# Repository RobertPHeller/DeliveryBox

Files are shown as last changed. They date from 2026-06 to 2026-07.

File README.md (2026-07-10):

# Delivery Box -- A lockable box for delivery prople to deliver stuff to.

This is a design for a delivery box -- a lockable box that delivery drivers
can place deliveries into, using one-time codes, where the delivery can be 
securely  housed  until the resident can retrieve  them.  This is to allow for
secure deliveries when noone is home to receive them.  The box will be
lockable and can be secured.  This will make deliveries secure from 
"porch pirates".

- [BoxDesign](BoxDesign/)

- [Circuit](Circuit/)

- [Firmware](DeliveryBoxFirmware/)

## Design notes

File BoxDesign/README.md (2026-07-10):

# This is the box design

The box would be made of CDX (exterier grade) 3/8 plywood with internier 2x2
framing, 20 inches by 24 inches by 30 inches, which should be large enough
for  more  deliveries.  It  will  have  wheels  to  make  moving  it  easy  --
partitularly handy for people with long driveways.

Here is a view of the box:

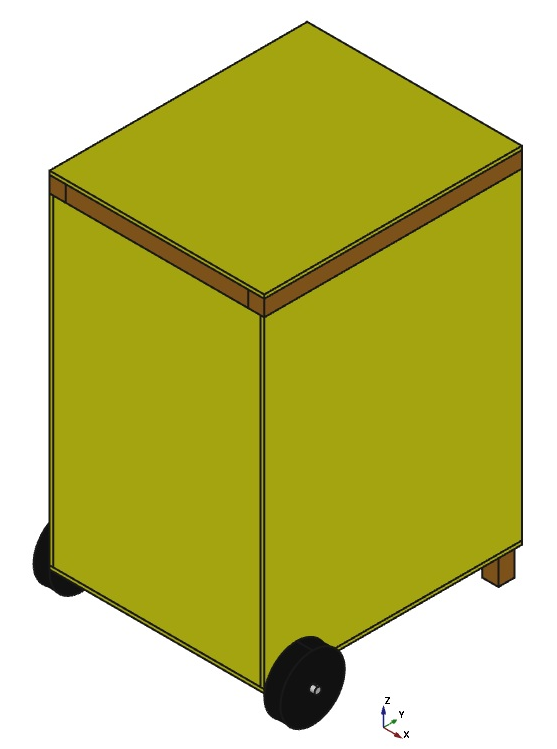
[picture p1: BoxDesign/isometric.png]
Isometric view of box


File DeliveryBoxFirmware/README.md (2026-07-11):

# This is the firmware

Target dev board: Adafruit Feather ESP32S3, No Psram version (8M flash).
 
This firmware manages the lock via a servo.  There is a numeric keypad and
an eight character 14-segment display.
 
The lock uses 8-digit codes to unlock the box.  There is one master code 
and any number of one-time codes.  The one time codes are given to delivery
drivers when a delivery is scheduled.  Once the driver uses the code to 
deliver the parcel, the code is removed and can't be used again.

The  firmware  can use  both  Blutooth  (BLE)  and  WiFi for  configuring  and
management.

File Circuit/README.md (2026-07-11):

# This is the circuit design

The circuit design uses these parts: 

1. A main board containing an Adafruit ESP32-S3 Feather and connection headers
for a servo  and the  keypad  (there is a  STEMMA/QWIC  connector  for the I2C
connection to the Display Module on th Feather board).  The Adafruit  ESP32-S3
Feather  includes a JST battery  connection and includes a LiPo battery charge
circuit.

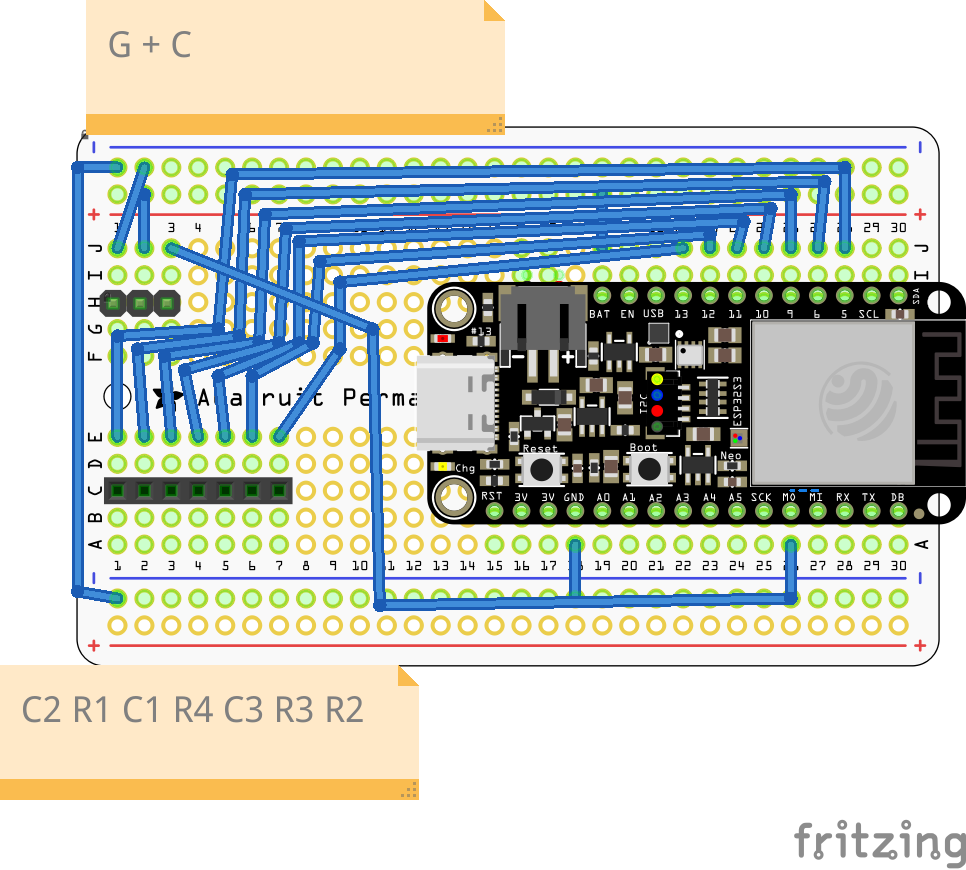
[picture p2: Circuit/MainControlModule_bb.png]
Main board fritzing module


2.  A  display  module  with  a  HT16K33   breakout  and  4  dual   14-segment
alphanumberic display modules.

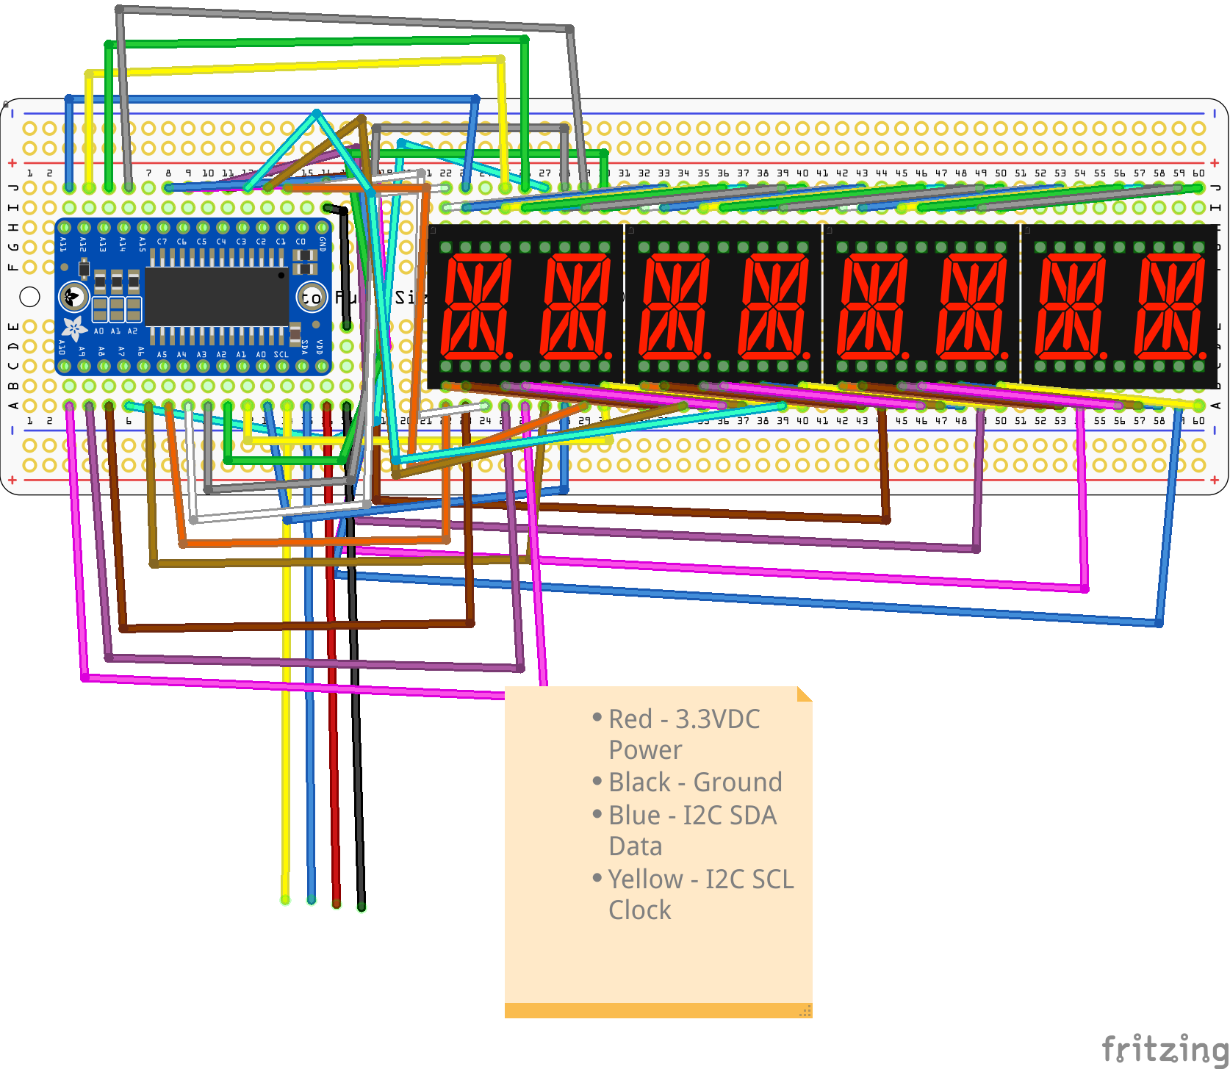
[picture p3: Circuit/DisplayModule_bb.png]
Display board fritzing module


3.  A 12-key keypad board.

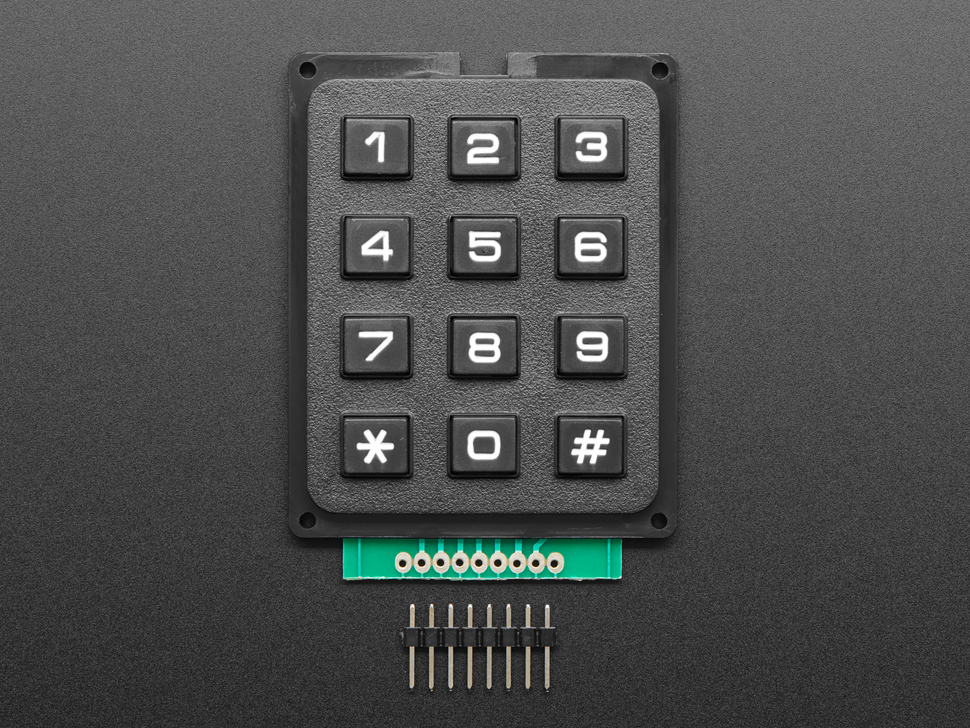
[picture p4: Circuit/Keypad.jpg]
3x4 Keypad


4. A high torque metal gear servo will be used to operate a lock.

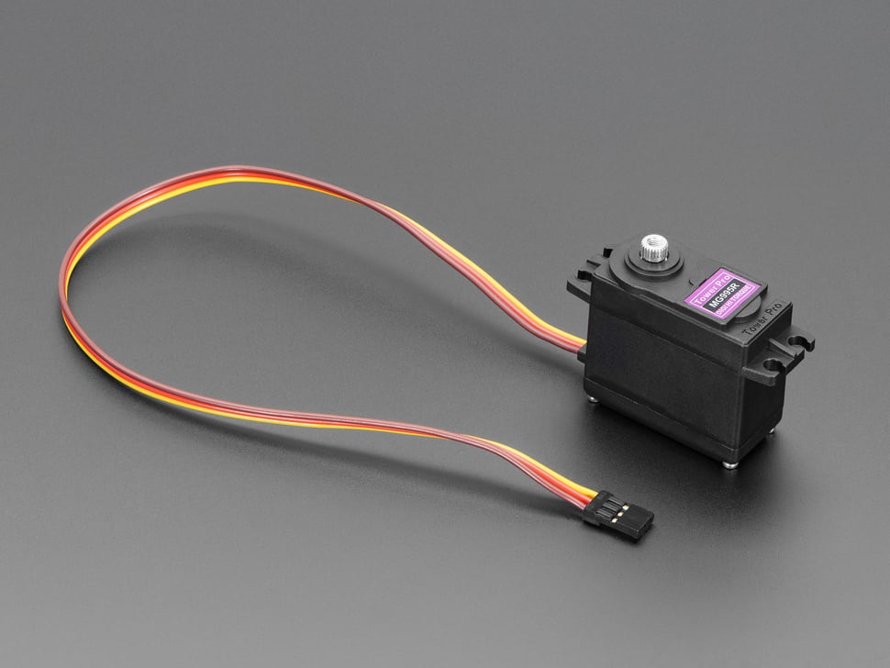
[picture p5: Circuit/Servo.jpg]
High Torque Servo


5. A LiPo battery

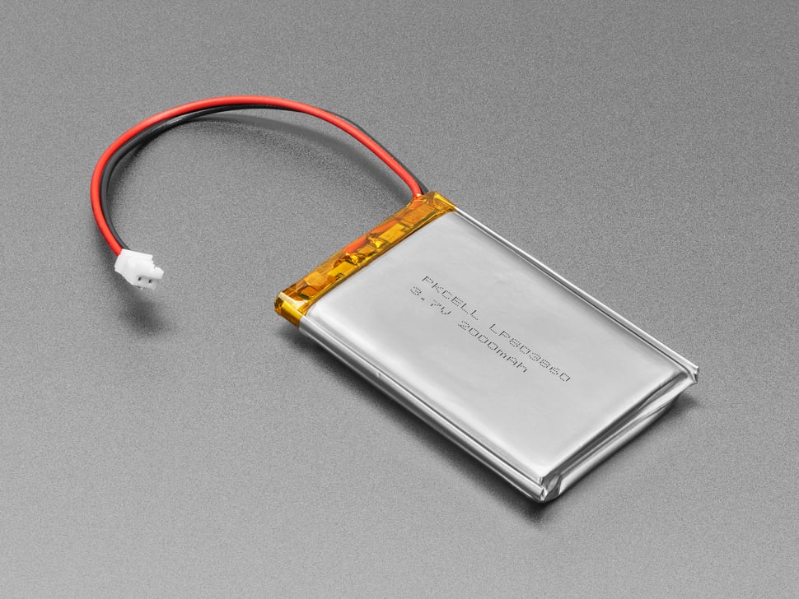
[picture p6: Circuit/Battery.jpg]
LiPo Battery


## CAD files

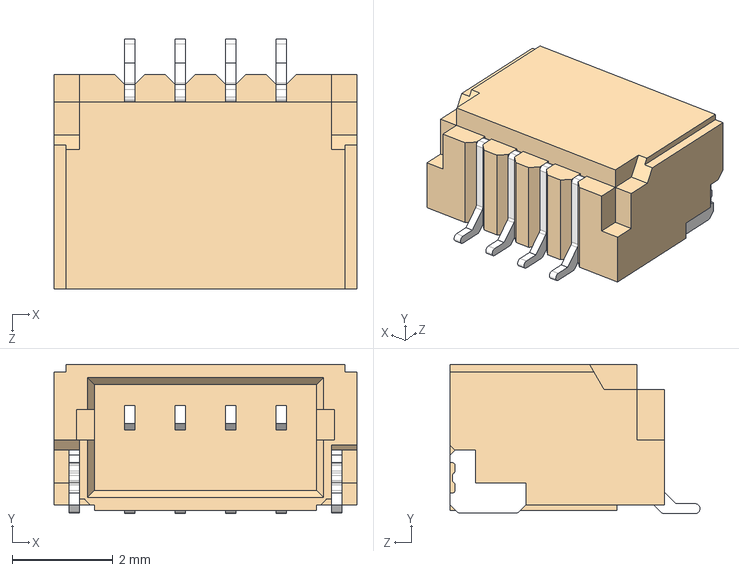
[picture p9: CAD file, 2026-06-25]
Circuit/DisplayModule/SM04B-SRSS-TB_LF__SN_.stp
6.00 x 2.96 x 4.95 mm

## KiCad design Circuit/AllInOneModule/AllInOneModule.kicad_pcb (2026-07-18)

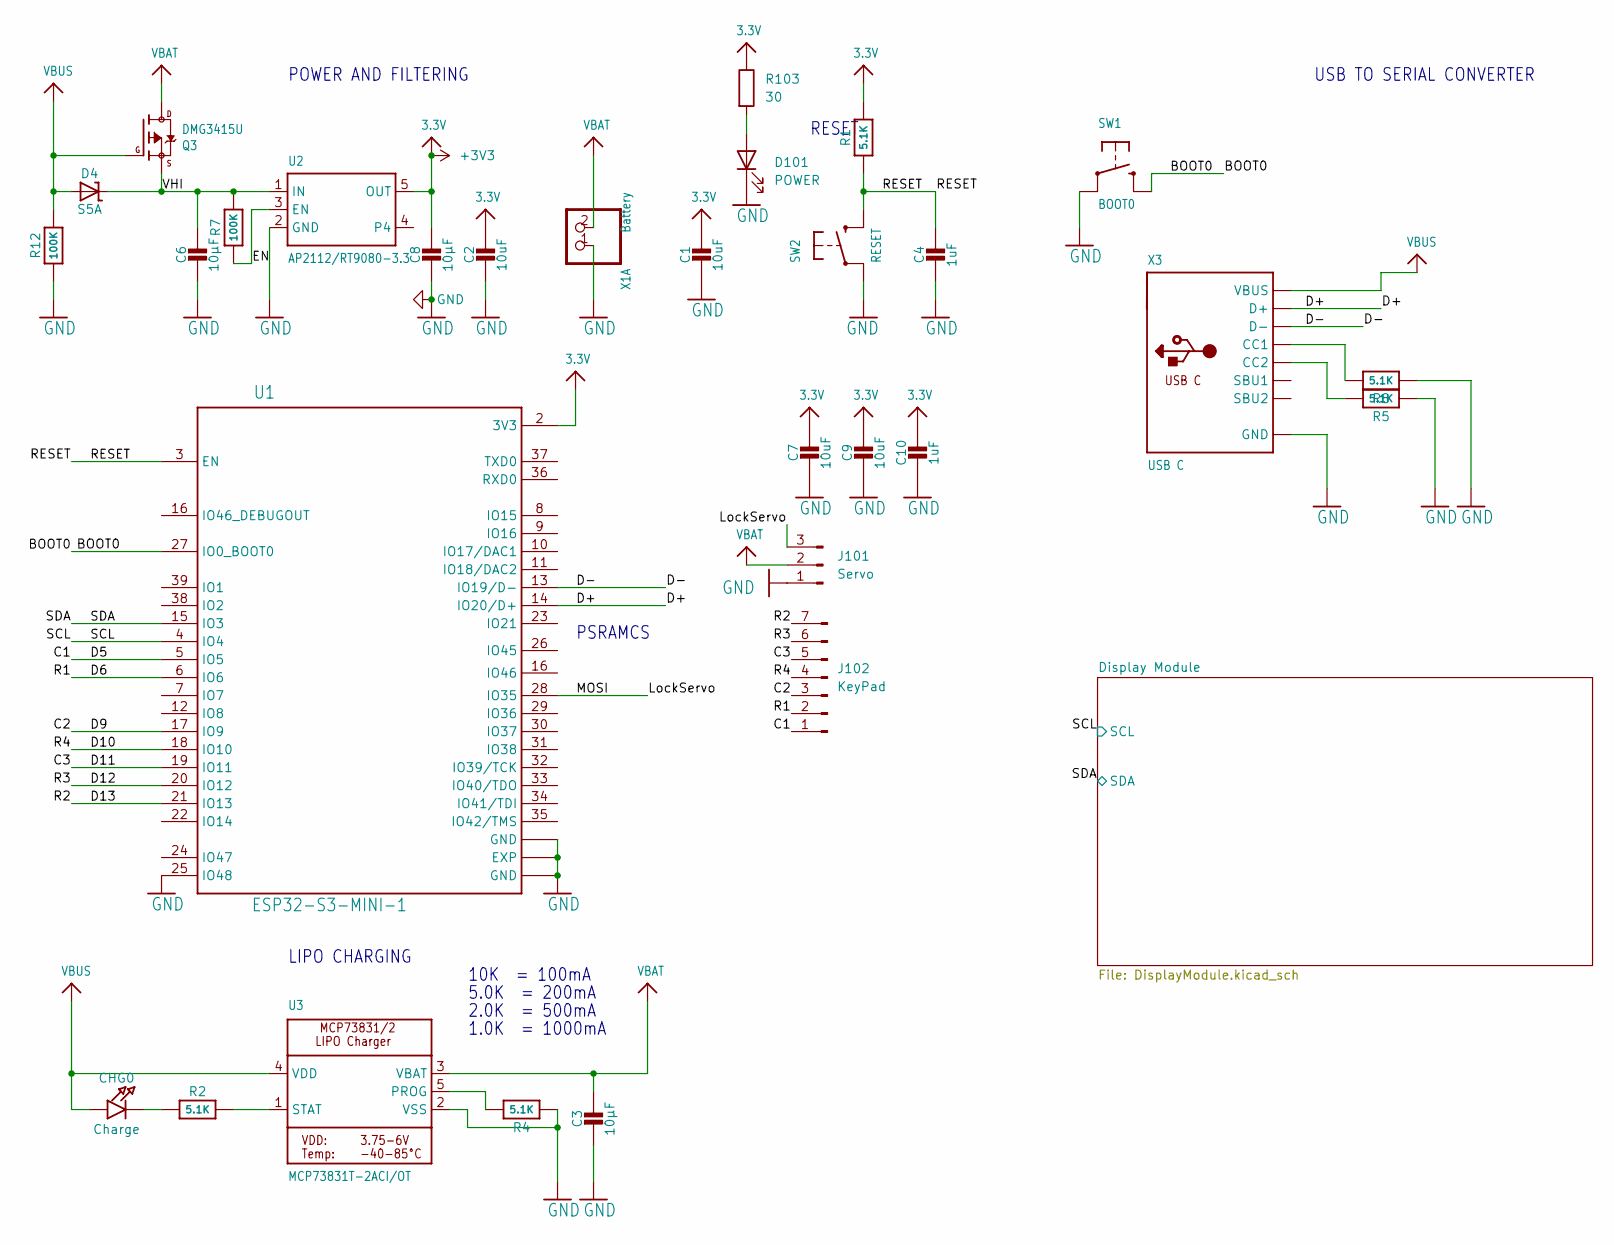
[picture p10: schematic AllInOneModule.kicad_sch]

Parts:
C1, C2, C7, C9: 10uF; C_0805_2012Metric; Mouser Part Number 187-CL21A106KQFNFNE
C3, C6, C8: 10µF; C_0805_2012Metric; Mouser Part Number 187-CL21A106KQFNFNE
C4, C10: 1uF; C_0603_1608Metric; Mouser Part Number 80-C0603C105K9PLR
CHG0: Charge; LED_0603_1608Metric; Mouser Part Number 859-LTST-C190KFKT
D4: S5A; S5AE357T; Mouser Part Number 637-S5A
D101: POWER; LED_0603_1608Metric; Mouser Part Number 604-AA1608ZGSK10MAV
J101: Servo; PinHeader_1x03_P2.54mm_Horizontal
J102: KeyPad; PinHeader_1x07_P2.54mm_Horizontal
Q3: DMG3415U; SOT-23-3; Mouser Part Number 621-DMG3415U-7
R1, R2, R4, R5, R8: 5.1K; R_0603_1608Metric; Mouser Part Number 603-RC0603JR-075K1P
R7, R12: 100K; R_0603_1608Metric; Mouser Part Number 603-RT0603DRD07100KL
R103: 30; R_0603_1608Metric; Mouser Part Number 603-AC0603JR-0730RL
SW1: BOOT0; SW_Push_1P1T_NO_CK_KMR2; Mouser Part Number 611-KMR211NGLFS
SW2: RESET; SW_Push_1P1T_NO_CK_KMR2; Mouser Part Number 611-KMR211NGLFS
U1: ESP32-S3-MINI-1; ESP32_S3_WROOM-1; Mouser Part Number 356-ESP32-S3-MINI1N8
U2: AP2112/RT9080-3.3; SOT-23-5; Mouser Part Number 621-AP2112K-3.3TRG1
U3: MCP73831T-2ACI/OT; SOT-23-5; Mouser Part Number 579-MCP73831T-2ACIOT
X1: Battery; JST_PH_S2B-PH-SM4-TB_1x02-1MP_P2.00mm_Horizontal; Mouser Part Number 306-S2BPHSM4TBLFSN
X3: USB C; CONN_USB4930-00-A_GCT; Mouser Part Number 640-USB4930-00-A

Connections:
+3V3: C1.1, C2.1, C7.1, C8.1, C9.1, C10.1, R1.2, R103.1, U1.2 (3V3), U2.5 (OUT); also elsewhere on the board
/BOOT0: SW1.2 (S1), U1.27 (IO0_BOOT0)
/C1: J102.1, U1.5 (IO5)
/C2: J102.3, U1.17 (IO9)
/C3: J102.5, U1.19 (IO11)
/D6: J102.2, U1.6 (IO6)
/D10: J102.4, U1.18 (IO10)
/D12: J102.6, U1.20 (IO12)
/D13: J102.7, U1.21 (IO13)
/D+: U1.14 (IO20/D+), X3.A6 (D+), X3.B6 (D+)
/D-: U1.13 (IO19/D-), X3.A7 (D-), X3.B7 (D-)
/EN: R7.1, U2.3 (EN)
/LockServo: J101.3, U1.28 (IO35)
/RESET: C4.1, R1.1, SW2.2 (S1), U1.3 (EN)
/SCL: U1.4 (IO4); also elsewhere on the board
/SDA: U1.15 (IO3); also elsewhere on the board
/VHI: C6.1, D4.2 (C), Q3.2 (S), R7.2, U2.1 (IN)
GND: C1.2, C2.2, C3.2, C4.2, C6.2, C7.2, C8.2, C9.2, C10.2, D101.1 (K), J101.1, R4.1, R5.1, R8.1, R12.1, SW1.1, SW2.1, U1.1 (GND), U1.25 (IO48), U1.40 (GND), U1.EPad (EXP), U2.2 (GND), U3.2 (VSS), X1.1, X3.A1 (GND), X3.A12 (GND), X3.B1 (GND), X3.B12 (GND); also elsewhere on the board
unnamed: CHG0.1 (C), R2.1
unnamed: D101.2 (A), R103.2
unnamed: R2.2, U3.1 (STAT)
unnamed: R4.2, U3.5 (PROG)
unnamed: R5.2, X3.B5 (CC2)
unnamed: R8.2, X3.A5 (CC1)
VBAT: C3.1, J101.2, Q3.3 (D), U3.3 (VBAT), X1.2
VBUS: CHG0.2 (A), D4.1 (A), Q3.1 (G), R12.2, U3.4 (VDD), X3.A4 (VBUS), X3.A9 (VBUS), X3.B4 (VBUS), X3.B9 (VBUS)

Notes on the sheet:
USB TO SERIAL CONVERTER
LIPO CHARGING
PSRAMCS
5.0K = 200mA
RESET
POWER AND FILTERING
10K = 100mA
2.0K = 500mA
1.0K = 1000mA

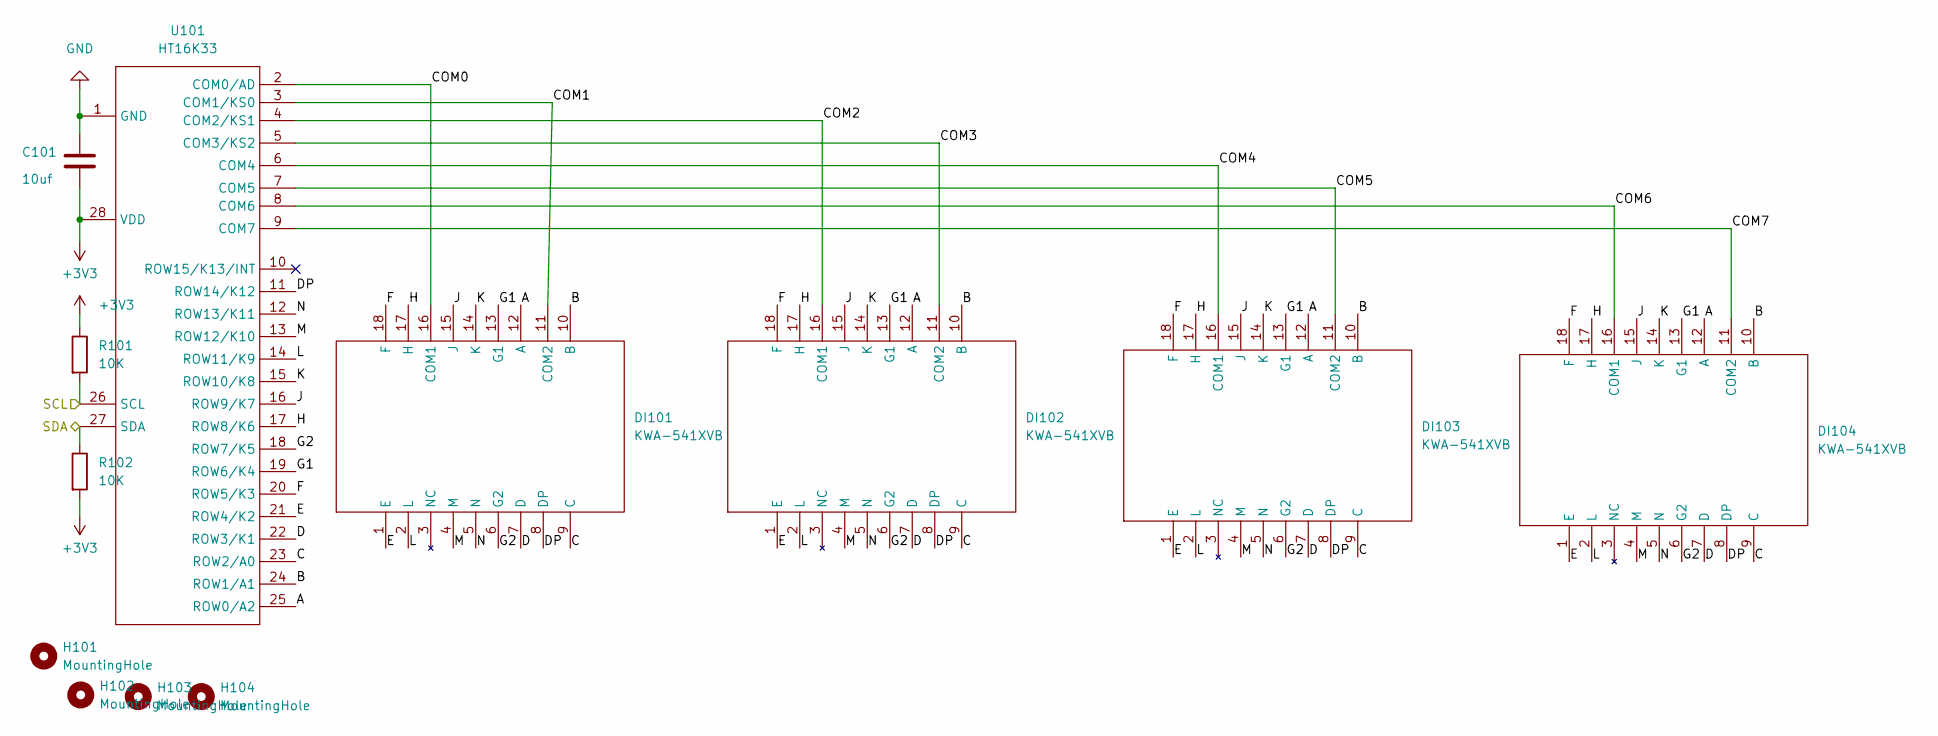
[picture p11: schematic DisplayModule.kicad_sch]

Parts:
C101: 10uf; C_0603_1608Metric; Mouser Part Number 963-JMK107ABJ106MA-T
DI101, DI102, DI103, DI104: KWA-541XVB
H101, H102, H103, H104: MountingHole; MountingHole_3.2mm_M3
R101, R102: 10K; R_0603_1608Metric; Mouser Part Number 603-AC0603JR-0710KL
U101: HT16K33; SOIC-28W_7.5x18.7mm_P1.27mm; Manufacturer Part Number HT16K33

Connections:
+3V3: C101.2, R101.1, R102.2, U101.28 (VDD); also elsewhere on the board
/Display Module/A: DI101.12 (A), DI102.12 (A), DI103.12 (A), DI104.12 (A), U101.25 (ROW0/A2)
/Display Module/B: DI101.10 (B), DI102.10 (B), DI103.10 (B), DI104.10 (B), U101.24 (ROW1/A1)
/Display Module/C: DI101.9 (C), DI102.9 (C), DI103.9 (C), DI104.9 (C), U101.23 (ROW2/A0)
/Display Module/COM0: DI101.16 (COM1), U101.2 (COM0/AD)
/Display Module/COM1: DI101.11 (COM2), U101.3 (COM1/KS0)
/Display Module/COM2: DI102.16 (COM1), U101.4 (COM2/KS1)
/Display Module/COM3: DI102.11 (COM2), U101.5 (COM3/KS2)
/Display Module/COM4: DI103.16 (COM1), U101.6 (COM4)
/Display Module/COM5: DI103.11 (COM2), U101.7 (COM5)
/Display Module/COM6: DI104.16 (COM1), U101.8 (COM6)
/Display Module/COM7: DI104.11 (COM2), U101.9 (COM7)
/Display Module/D: DI101.7 (D), DI102.7 (D), DI103.7 (D), DI104.7 (D), U101.22 (ROW3/K1)
/Display Module/DP: DI101.8 (DP), DI102.8 (DP), DI103.8 (DP), DI104.8 (DP), U101.11 (ROW14/K12)
/Display Module/E: DI101.1 (E), DI102.1 (E), DI103.1 (E), DI104.1 (E), U101.21 (ROW4/K2)
/Display Module/F: DI101.18 (F), DI102.18 (F), DI103.18 (F), DI104.18 (F), U101.20 (ROW5/K3)
/Display Module/G1: DI101.13 (G1), DI102.13 (G1), DI103.13 (G1), DI104.13 (G1), U101.19 (ROW6/K4)
/Display Module/G2: DI101.6 (G2), DI102.6 (G2), DI103.6 (G2), DI104.6 (G2), U101.18 (ROW7/K5)
/Display Module/H: DI101.17 (H), DI102.17 (H), DI103.17 (H), DI104.17 (H), U101.17 (ROW8/K6)
/Display Module/J: DI101.15 (J), DI102.15 (J), DI103.15 (J), DI104.15 (J), U101.16 (ROW9/K7)
/Display Module/K: DI101.14 (K), DI102.14 (K), DI103.14 (K), DI104.14 (K), U101.15 (ROW10/K8)
/Display Module/L: DI101.2 (L), DI102.2 (L), DI103.2 (L), DI104.2 (L), U101.14 (ROW11/K9)
/Display Module/M: DI101.4 (M), DI102.4 (M), DI103.4 (M), DI104.4 (M), U101.13 (ROW12/K10)
/Display Module/N: DI101.5 (N), DI102.5 (N), DI103.5 (N), DI104.5 (N), U101.12 (ROW13/K11)
/SCL: R101.2, U101.26 (SCL); also elsewhere on the board
/SDA: R102.1, U101.27 (SDA); also elsewhere on the board
GND: C101.1, U101.1 (GND); also elsewhere on the board

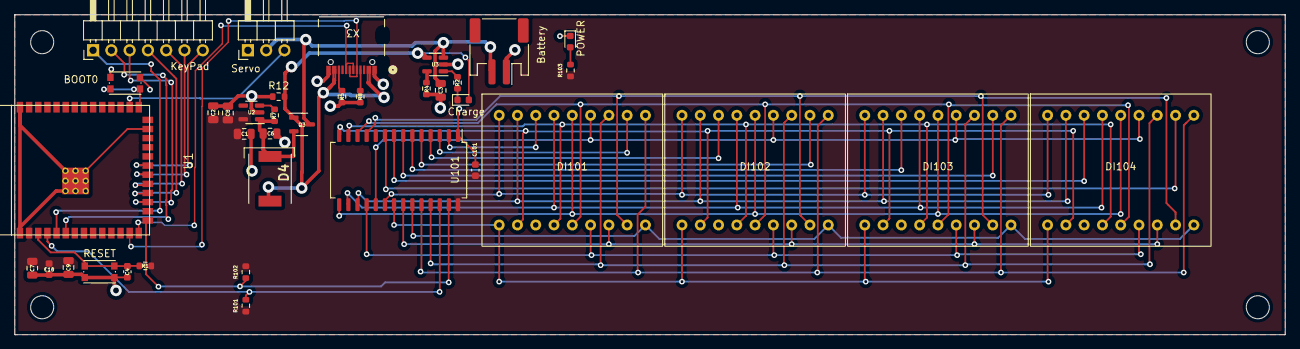
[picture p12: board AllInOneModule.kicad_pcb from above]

Board: 2 copper layers, 176.5 x 44.5 mm, 42 parts (0 on the bottom side), 49 nets.

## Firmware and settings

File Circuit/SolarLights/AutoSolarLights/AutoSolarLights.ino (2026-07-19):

// A basic everyday NeoPixel strip test program.

// NEOPIXEL BEST PRACTICES for most reliable operation:
// - Add 1000 uF CAPACITOR between NeoPixel strip's + and - connections.
// - MINIMIZE WIRING LENGTH between microcontroller board and first pixel.
// - NeoPixel strip's DATA-IN should pass through a 300-500 OHM RESISTOR.
// - AVOID connecting NeoPixels on a LIVE CIRCUIT. If you must, ALWAYS
//   connect GROUND (-) first, then +, then data.
// - When using a 3.3V microcontroller with a 5V-powered NeoPixel strip,
//   a LOGIC-LEVEL CONVERTER on the data line is STRONGLY RECOMMENDED.
// (Skipping these may work OK on your workbench but can fail in the field)

#include <Adafruit_NeoPixel.h>
#ifdef __AVR__
 #include <avr/power.h> // Required for 16 MHz Adafruit Trinket
#endif

// Which pin on the Arduino is connected to the NeoPixels?
// On a Trinket or Gemma we suggest changing this to 1:
#define LED_PIN    5

// How many NeoPixels are attached to the Arduino?
// 68 inches of 32/meter
#define LED_COUNT 55 

// Declare our NeoPixel strip object:
Adafruit_NeoPixel strip(LED_COUNT, LED_PIN, NEO_GRB + NEO_KHZ800);
// Argument 1 = Number of pixels in NeoPixel strip
// Argument 2 = Arduino pin number (most are valid)
// Argument 3 = Pixel type flags, add together as needed:
//   NEO_KHZ800  800 KHz bitstream (most NeoPixel products w/WS2812 LEDs)
//   NEO_KHZ400  400 KHz (classic 'v1' (not v2) FLORA pixels, WS2811 drivers)
//   NEO_GRB     Pixels are wired for GRB bitstream (most NeoPixel products)
//   NEO_RGB     Pixels are wired for RGB bitstream (v1 FLORA pixels, not v2)
//   NEO_RGBW    Pixels are wired for RGBW bitstream (NeoPixel RGBW products)


#define LDRPIN A0

// setup() function -- runs once at startup --------------------------------

void setup() {
  // These lines are specifically to support the Adafruit Trinket 5V 16 MHz.
  // Any other board, you can remove this part (but no harm leaving it):
#if defined(__AVR_ATtiny85__) && (F_CPU == 16000000)
  clock_prescale_set(clock_div_1);
#endif
  // END of Trinket-specific code.

    strip.begin();           // INITIALIZE NeoPixel strip object (REQUIRED)
    strip.show();            // Turn OFF all pixels ASAP
    strip.setBrightness(50); // Set BRIGHTNESS to about 1/5 (max = 255)
    
    
}


// loop() function -- runs repeatedly as long as board is on ---------------

void loop() {
    
    int photocellReading = analogRead(LDRPIN);  
    if (photocellReading < 512)
    {
        theaterChaseRainbow(50); // Rainbow-enhanced theaterChase variant
    }
    else
    {
        delay(1000);
    }
}


// Some functions of our own for creating animated effects -----------------

// Rainbow-enhanced theater marquee. Pass delay time (in ms) between frames.
void theaterChaseRainbow(int wait) {
  int firstPixelHue = 0;     // First pixel starts at red (hue 0)
  for(int a=0; a<30; a++) {  // Repeat 30 times...
    for(int b=0; b<3; b++) { //  'b' counts from 0 to 2...
      strip.clear();         //   Set all pixels in RAM to 0 (off)
      // 'c' counts up from 'b' to end of strip in increments of 3...
      for(int c=b; c<strip.numPixels(); c += 3) {
        // hue of pixel 'c' is offset by an amount to make one full
        // revolution of the color wheel (range 65536) along the length
        // of the strip (strip.numPixels() steps):
        int      hue   = firstPixelHue + c * 65536L / strip.numPixels();
        uint32_t color = strip.gamma32(strip.ColorHSV(hue)); // hue -> RGB
        strip.setPixelColor(c, color); // Set pixel 'c' to value 'color'
      }
      strip.show();                // Update strip with new contents
      delay(wait);                 // Pause for a moment
      firstPixelHue += 65536 / 90; // One cycle of color wheel over 90 frames
    }
  }
}

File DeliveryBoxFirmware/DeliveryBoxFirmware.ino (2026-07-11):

// -!- C++ -!- //////////////////////////////////////////////////////////////
//
//  System        : 
//  Module        : 
//  Object Name   : $RCSfile$
//  Revision      : $Revision$
//  Date          : $Date$
//  Author        : $Author$
//  Created By    : Robert Heller
//  Created       : 2026-06-17 06:23:17
//  Last Modified : <260711.0733>
//
//  Description	
//
//  Notes
//
//  History
//	
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
//
//////////////////////////////////////////////////////////////////////////////

/** @mainpage Delivery Box Firmware 
 * A lockable box for delivery prople to deliver stuff to.
 * 
 * Target dev board: Adafruit Feather ESP32S3, No Psram version (8M flash).
 * 
 * This firmware manages the lock via a servo.  There is a numeric keypad and
 * an eight character 14-segment display.
 * 
 * The lock uses 8-digit codes to unlock the box.  There is one master code 
 * and any number of one-time codes.  The one time codes are given to delivery
 * drivers when a delivery is scheduled.  Once the driver uses the code to 
 * deliver the parcel, the code is removed and can't be used again.
 * 
 * 
 */

static const char rcsid[] = "@(#) : $Id$";

#include <Arduino.h>
#include <WebServer.h>
#include <WiFi.h>
#include "BluetoothSerial.h"
#include <ESPmDNS.h>
#include <Adafruit_Keypad.h>
#include <Adafruit_LEDBackpack.h>
#include <ESP32Servo.h>
#include "GPIO_MAP.h"
#include "Networking.h"
#include "DeliveryBoxWebserver.h"
#include <FS.h>
#include <SPIFFS.h>
#include "LockServo.h"
#include "Display.h"
#include "Keypad4x3.h"
#include "LockProcess.h"

void listDir(fs::FS &fs, const char *dirname, uint8_t levels) {
  Serial.printf("Listing directory: %s\r\n", dirname);

  File root = fs.open(dirname);
  if (!root) {
    Serial.println("- failed to open directory");
    return;
  }
  if (!root.isDirectory()) {
    Serial.println(" - not a directory");
    return;
  }

  File file = root.openNextFile();
  while (file) {
    if (file.isDirectory()) {
      Serial.print("  DIR : ");
      Serial.println(file.name());
      if (levels) {
        listDir(fs, file.path(), levels - 1);
      }
    } else {
      Serial.print("  FILE: ");
      Serial.print(file.name());
      Serial.print("\tSIZE: ");
      Serial.println(file.size());
    }
    file = root.openNextFile();
  }
}


/** @brief Intialize everything.
 * - Start the serial port
 * - Mount the SPI File System
 * @returns nothing.
 */
void setup() {
    // put your setup code here, to run once:
    pinMode(BUILTIN_LED,OUTPUT);
    digitalWrite(BUILTIN_LED,HIGH);
    Serial.begin(115200);
    rgbLedWrite(RGB_BUILTIN,0,255,0);
    unsigned char led = 0;
    if(!SPIFFS.begin(true)) {
        Serial.printf("Failed to mount SPIFFS!\n");
        while (1) 
        {
            Serial.printf("!");
            rgbLedWrite(RGB_BUILTIN,led++,0,0);
            delay(100);
        }
    }
    rgbLedWrite(RGB_BUILTIN,0,0,255);
    listDir(SPIFFS,"/",0);
    rgbLedWrite(RGB_BUILTIN,0,0,0);
    Networking::Initialize();
    // Keypad init
    Keypad4x3::Keypad4x3::Initialize();
    // Display init
    Display::Display::InitDisplay();
    // Lock init
    LockServo::LockServo::Initialize();
    LockProcess::LockProcess::Initialize();
    
}

/** @brief Main loop.
 * @returns nothing.
 */
void loop() {
    // put your main code here, to run repeatedly:
    Keypad4x3::Keypad4x3::instance()->tick();
    while (Keypad4x3::Keypad4x3::instance()->available())
    {
        keypadEvent e = Keypad4x3::Keypad4x3::instance()->read();
        if(e.bit.EVENT == KEY_JUST_PRESSED)
        {
            LockProcess::LockProcess::ProcessKey(e.bit.KEY);
        }
    }
    BackgroundTask::RunTasks(10);
}    

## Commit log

2026-06-18 Create Display Module with Fritzing
    [DisplayModule.fzz]
2026-06-19 Add main control module.
    [MainControlModule.fzz]
2026-06-19 Snapshot commit.
    [partitions.csv]
2026-06-25 Design PCB for display module.
    [DisplayModule.kicad_pcb, DisplayModule.kicad_sch, SM04B-SRSS-TB_LF__SN_.stp]
2026-06-27 PCB Completed.
2026-06-30 Updated Fritzing version of Display Module.
    [DisplayModule.fzz]
2026-07-10 Add wheels and axle.
2026-07-16 Started All In One Module.
    [AllInOneModule.kicad_pcb, AllInOneModule.kicad_sch, DisplayModule.kicad_sch]
2026-07-18 Nearly Complete Circuit Boards.
    [AllInOneModule.kicad_pcb, DisplayModule.kicad_pcb]
2026-07-18 Add Solar Lights Fritzing.
    [SolarLights.fzz]
2026-07-19 Firmware for Solar Lights.
    [SolarLights.fzz]

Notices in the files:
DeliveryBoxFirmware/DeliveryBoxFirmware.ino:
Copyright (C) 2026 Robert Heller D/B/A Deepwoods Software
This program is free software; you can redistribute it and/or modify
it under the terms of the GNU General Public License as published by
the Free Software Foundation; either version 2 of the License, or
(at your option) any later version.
